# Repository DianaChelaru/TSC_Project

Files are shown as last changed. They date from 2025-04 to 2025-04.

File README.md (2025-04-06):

Acest proiect îmbină mai multe componente electronice conectate la un microcontroler ESP32-C6-WROOM-1-N8, creând o platformă embedded compactă destinată aplicațiilor cu senzoristică, comunicație wireless și o interfață de utilizator minimală. Platforma poate gestiona o serie de funcționalități, inclusiv monitorizarea și interacțiunea cu date în timp real, gestionarea energiei și stocarea datelor.

    Bill of Materials
|Componenta	|Link|	Datasheet|
|---|---|---|
|112A-TAAR-R03_ATTEND |	https://store.comet.bg/en/Catalogue/Product/43497/ |	https://store.comet.bg/en/Catalogue/Product/43497/ |
|744043680IND_4828-WE-TPC_WRE |	https://www.digikey.sg/en/models/1638515 |	https://www.we-online.com/components/products/datasheet/744043680.pdf |
|ADAFRUIT_LEDCHIP-LED0603 |	https://www.snapeda.com/parts/KP-1608SURCK/Kingbright/view-part/?ref=search&t=LED%200603 |	https://www.snapeda.com/parts/KP-1608SURCK/Kingbright/datasheet/ |  
|SAMACSYS_PARTS_USB4110-GF-A|	https://componentsearchengine.com/part-view/USB4110-GF-A/GCT%20(GLOBAL%20CONNECTOR%20TECHNOLOGY) |	https://gct.co/files/drawings/usb4110.pdf |
|BD5229G-TR|	https://componentsearchengine.com/part-view/BD5229G-TR/ROHM%20Semiconductor |	https://datasheet.datasheetarchive.com/originals/distributors/Datasheets_SAMA/f2b9741ef86007909f138d561a359946.pdf |
|CPH3225A|	https://www.snapeda.com/parts/CPH3225A/Seiko+Instruments/view-part/?ref=eda |	https://www.snapeda.com/parts/CPH3225A/Seiko%20Instruments/datasheet/ |
|QWIIC_CONNECTORJS-1MM|	https://www.snapeda.com/parts/PRT-14417/SparkFun/view-part/ |	https://www.snapeda.com/parts/PRT-14417/SparkFun%20Electronics/datasheet/ |
|BUTTON_CUSYOMV1|	https://industry.panasonic.com/global/en/downloads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	| https://industry.panasonic.com/global/en/downloads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 |
|ESP32_WROVER_EAGLE-LTSPICE_CC0402|	https://componentsearchengine.com/part-view/CC0402MRX5R5BB106/YAGEO |	https://componentsearchengine.com/Datasheets/2/CC0402MRX5R5BB106.pdf |
|CPH3225A|	https://www.snapeda.com/parts/CPH3225A/Seiko+Instruments/view-part/?ref=eda |	https://www.snapeda.com/parts/CPH3225A/Seiko%20Instruments/datasheet/ |
|DS3231SN|	https://www.snapeda.com/parts/DS3231SN%23/Analog+Devices/view-part/?ref=eda |	https://www.snapeda.com/parts/DS3231SN%23/Analog%20Devices/datasheet/ |
|ESP32_WROVER_EAGLE-LTSPICE_RR0402|	https://www.snapeda.com/parts/RC0402FR-07226RL/Yageo/view-part/	| https://www.snapeda.com/parts/RC0402FR-07226RL/Yageo/datasheet/ |
|ESP32_WROVER_BME680_BME680|	https://www.snapeda.com/parts/BME680/Bosch/view-part/?welcome=home |	https://www.snapeda.com/parts/BME680/Bosch%20Sensortec/datasheet/ |
|ESP32_WROVER_EAGLE-LTSPICE_CC0402|	https://componentsearchengine.com/Datasheets/2/CC0402MRX5R5BB106.pdf |	https://componentsearchengine.com/part-view/CC0402MRX5R5BB106/YAGEO |
|ESP32_WROVER_SPARKFUN-DISCRETESEMI_MOSFET_PCH-DMG2305UX-7|	https://componentsearchengine.com/part-view/DMG2305UX-7/Diodes%20Incorporated |	https://www.diodes.com//assets/Datasheets/DMG2305UX.pdf |
|ESP32C6_VARISTORCN1812|	https://www.mouser.co.uk/ProductDetail/EPCOS-TDK/B72520T0350K062?qs=dEfas%2FXlABIszF52uu7vrg%3D%3D	| https://www.tdk-electronics.tdk.com/inf/75/db/CTVS_14/Surge_protection_series.pdf |
|ESP32-C6-WROOM-1-N8| 	https://www.snapeda.com/parts/ESP32-C6-WROOM-1-N8/Espressif+Systems/view-part/?ref=eda |	https://www.snapeda.com/parts/ESP32-C6-WROOM-1-N8/Espressif%20Systems/datasheet/ |
|FH34SRJ-24S-0.5SH_99_ |	https://componentsearchengine.com/part-view/XC6220A331MR-G/Torex	| https://product.torexsemi.com/system/files/series/xc6220.pdf |
|MAX17048G+T10|	https://www.snapeda.com/parts/MAX17048G+T10/Analog+Devices/view-part/?ref=eda |	https://www.snapeda.com/parts/MAX17048G+T10/Analog%20Devices/datasheet/ |
|MBR0530|	https://ro.mouser.com/ProductDetail/KYOCERA-AVX/SD0805S020S1R0?qs=jCA%252BPfw4LHbpkAoSnwrdjw%3D%3D |	https://ro.mouser.com/datasheet/2/40/schottky-3165252.pdf |
|PGB1010603MR|	https://www.snapeda.com/parts/PGB1010603MR/Littelfuse/view-part/?ref=eda |	https://www.snapeda.com/parts/PGB1010603MR/Littelfuse%20Inc./datasheet/ |
|MCP73831 |	https://www.digikey.com/en/models/1874108 |	https://ww1.microchip.com/downloads/aemDocuments/documents/APID/ProductDocuments/DataSheets/MCP73831-Family-Data-Sheet-DS20001984H.pdf |
|RCL_CPOL-EUCT3528|	https://ro.mouser.com/ProductDetail/Vishay-Sprague/TR3B106K025C1300?qs=jCGqFXxTmLdffnuDkXzk1g%3D%3D |	https://www.vishay.com/docs/40080/tr3.pdf |
|SI1308EDL-T1-GE3|	https://componentsearchengine.com/part-view/SI1308EDL-T1-GE3/Vishay	| https://componentsearchengine.com/Datasheets/1/SI1308EDL-T1-GE3.pdf |
| SJ |	https://grabcad.com/library/solder-jumpers-1 | 
|USBLC6-2SC6Y |	https://www.snapeda.com/parts/USBLC6-2SC6Y/STMicroelectronics/view-part/?ref=eda	| https://www.snapeda.com/parts/USBLC6-2SC6Y/STMicroelectronics/datasheet/ |
|W25Q512JVEIQ|	https://www.snapeda.com/parts/W25Q512JVEIQ/Winbond+Electronics/view-part/?ref=eda |	https://www.snapeda.com/parts/W25Q512JVEIQ/Winbond%20Electronics/datasheet/ |
|XC6220A331MR-G|	https://componentsearchengine.com/part-view/XC6220A331MR-G/Torex |	https://product.torexsemi.com/system/files/series/xc6220.pdf|

    1. Microcontrolerul ESP32-C6-WROOM-1-N8
Descriere: Acesta este nucleul sistemului nostru și va gestiona toată logica și comunicațiile. Este un microcontroler cu suport pentru Wi-Fi și Bluetooth Low Energy (BLE), având o capacitate de procesare ridicată și multiple periferice integrate.

Componente hardware conectate:

Pinout: Conectarea senzorilor și modulelor va depinde de alegerea pinilor pe care i-am selectat pe ESP32, detaliată în documentație.

Interfețe: ESP32 folosește interfețe precum I2C, SPI și UART pentru a comunica cu componentele periferice.

    2. Senzori
Senzor de temperatură și umiditate (ex. DHT22):

Interfață: Digitală

Rol: Măsurarea temperaturii și umidității în mediu.

Comunicare: Acesta va comunica cu ESP32 folosind pinul GPIO (general-purpose input/output) pentru a obține valorile măsurate.

Senzor de lumină (ex. LDR):

Interfață: Analogică

Rol: Măsurarea intensității luminii din mediu.

Comunicare: Va fi conectat la un pin analogic al ESP32 pentru a permite citirea valorilor de lumină.

    3. RTC (Real-Time Clock)
Componente: Modul RTC (de exemplu, DS3231)

Interfață: I2C

Rol: Ținerea orei și datei, chiar și când microcontrolerul este alimentat cu baterie.

Comunicare: ESP32 se va conecta la RTC prin interfața I2C. Datele și ora vor fi extrase periodic din RTC pentru a menține sincronizarea corectă a sistemului.

    4. Memorie Externă
Componente: Modul de memorie flash (ex. SPI Flash)

Interfață: SPI

Rol: Stocarea datelor de configurare, date temporare, sau orice altă informație care trebuie păstrată între restarturi ale sistemului.

Comunicare: Memoria externă va comunica cu ESP32 prin interfața SPI, permițând citirea și scrierea rapidă a datelor.

    5. Alimentare și Managementul Energiei
Componente:

Regulator de tensiune: Acesta va asigura alimentarea stabilă a întregului sistem.

Baterie Li-Ion: O baterie de 3.7V va fi utilizată pentru a alimenta sistemul într-un mod eficient.

Consumul de Energie:

ESP32 este un microcontroler cu consum variabil, dar în mod normal consumă aproximativ 160 mA în mod activ și mult mai puțin în modul de adormire. Prin gestionarea corectă a modurilor de adormire, se poate reduce consumul total de energie la un nivel foarte scăzut.

Optimizare: Implementarea unui algoritm de gestionare a energiei va permite microcontrolerului să intre în moduri de adormire adâncă în timpul perioadelor de inactivitate, economisind astfel energie.

    6. Interfețe de Comunicație
Wi-Fi (IEEE 802.11b/g/n): ESP32 va fi capabil să comunice prin rețele Wi-Fi pentru a trimite date la servere sau pentru a se conecta la alte dispozitive.

Bluetooth Low Energy (BLE): Pentru comunicații cu alte dispozitive Bluetooth, cum ar fi smartphone-uri sau alte sisteme integrate.

    7. Protecții și Siguranță
Protecție la supratensiune și supracurent: Sistemul va include diode și rezistențe de protecție pentru a preveni daunele cauzate de condiții de tensiune necontrolată.

Siguranța bateriei: Managementul bateriei va include circuite de protecție pentru a preveni supraîncărcarea sau descărcarea excesivă.

    ⚡ Calcule de consum
Acestea sunt estimările de consum pentru fiecare componentă principală a platformei:

ESP32-C6 în modul activ: Aproximativ 80 mA.

Senzori activi (maxim): Între 10-20 mA.

În modul standby: Sub 10 mA, cu ESP în deep sleep și senzorii inactivi.

MCP73831 (încărcare): Până la 500 mA, în funcție de configurare.

Consum optimizat:

LDO XC6220A331MR-G, care este eficient la sarcini joase.

Mod de deep sleep al ESP32-C6 între măsurători.

Control MOSFET pentru a alimenta perifericele doar când este necesar.

    🔌 Pini folosiți pe ESP32-C6
Acestea sunt conexiunile pinilor ESP32-C6 la diversele componente ale proiectului:

|Pin ESP32-C6 |	Funcție	  | Conectat la|
|---|---|---|
|GPIO0 	  |  Buton USER	| BUTTON_CUSTOMV1|
|GPIO1 (TX)  |	UART TX	 | USB4110-GF-A|
|GPIO2 (RX)	 | UART RX	  | USB4110-GF-A|
|GPIO3	 | SDA I2C	  | BME680, DS3231, MAX17048|
|GPIO4	 |  SCL I2C	  | BME680, DS3231, MAX17048|
|GPIO5	 | SPI CS	 |  W25Q512JVEIQ|
|GPIO6	 |  SPI CLK	  | W25Q512JVEIQ|
|GPIO7	 |  SPI MISO	  |  W25Q512JVEIQ|
|GPIO8	 |  SPI MOSI	  |  W25Q512JVEIQ|
|GPIO9	 |  LED	 | ADAFRUIT_LEDCHIP-LED0603|
|GPIO10	 |  MOSFET control |	SI1308EDL-T1-GE3|

diagrama-1

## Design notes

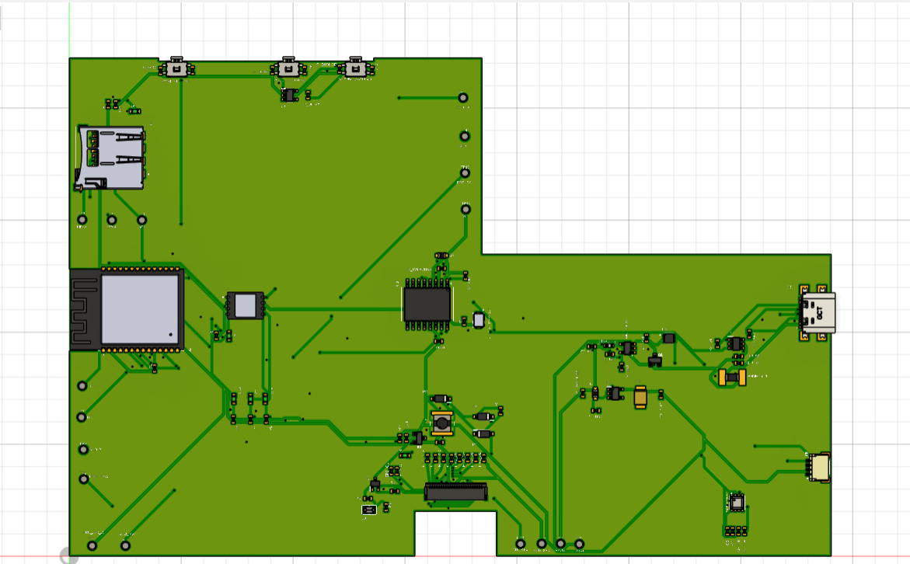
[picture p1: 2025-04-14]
Images/Screenshot 2025-04-14 195516.png

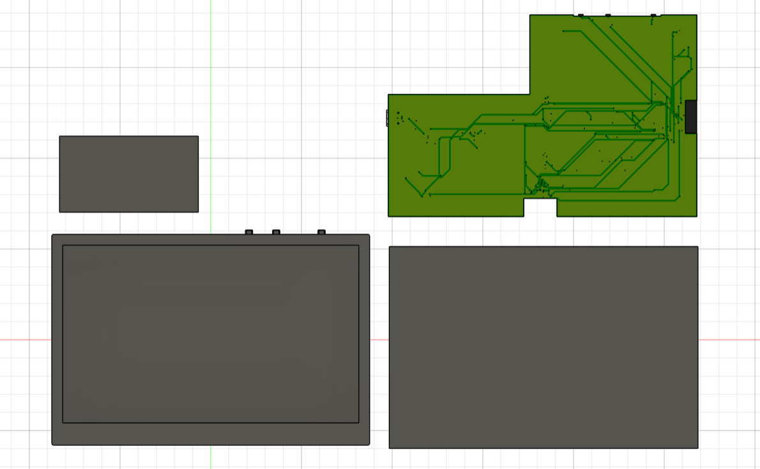
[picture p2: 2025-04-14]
Images/Screenshot 2025-04-11 104446.png

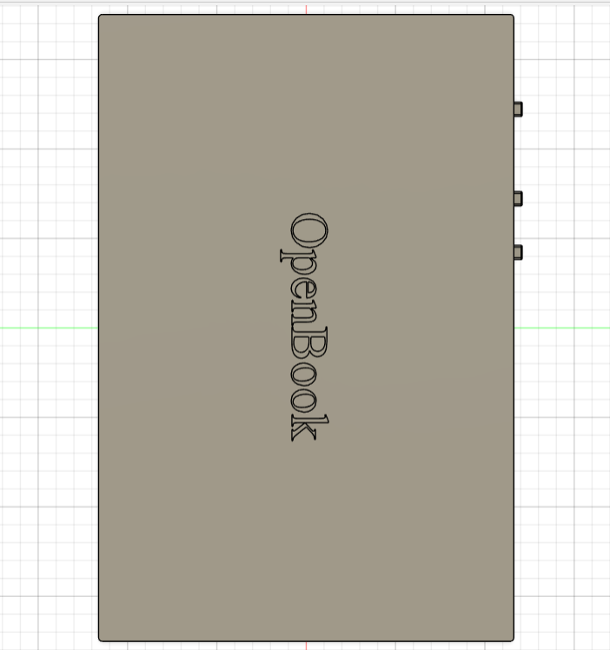
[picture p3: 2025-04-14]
Images/Screenshot 2025-04-11 121247.png

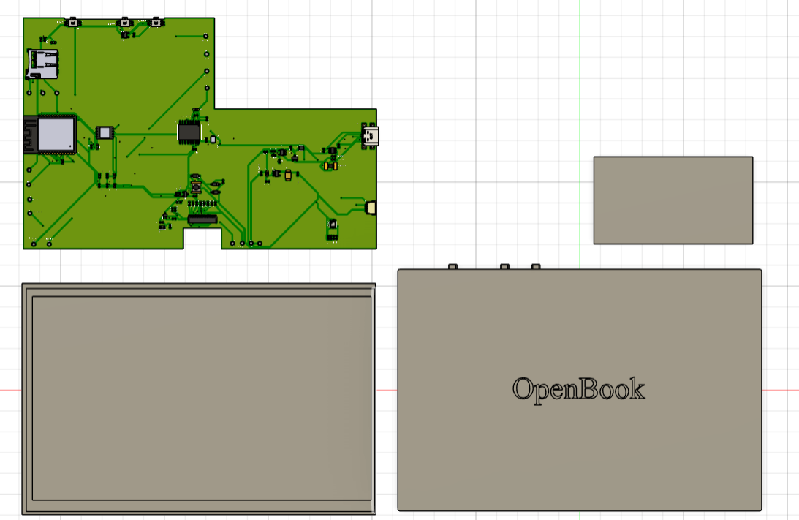
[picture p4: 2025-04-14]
Images/Screenshot 2025-04-11 104347.png

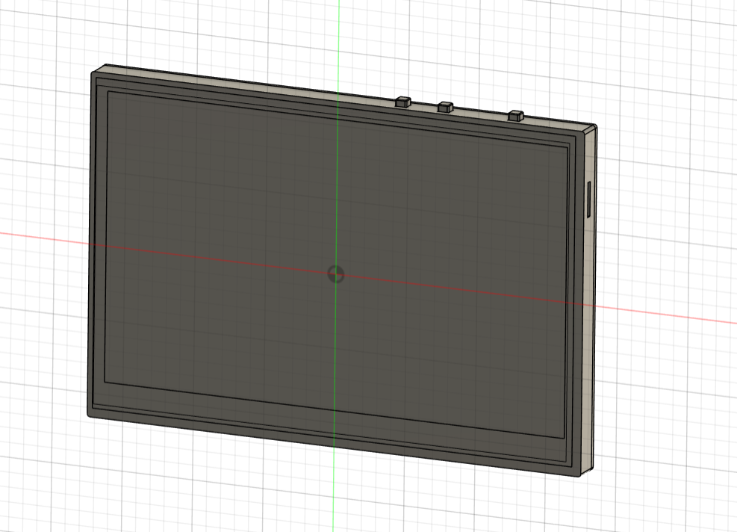
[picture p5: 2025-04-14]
Images/Screenshot 2025-04-11 121353.png

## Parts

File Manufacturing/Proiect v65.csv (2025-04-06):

Qty | Value | Device | Package | Parts | Description | 3V3 | ARROW_PART_NUMBER | ARROW_PRICE-STOCK | AVAILABILITY | CENTROID_NOT_SPECIFIED | CHECK_PRICES | COPYRIGHT | DATASHEET | DESCRIPTION | DIGIKEY_DESCRIPTION | DIGIKEY_PART_NUMBER | EPD_3V3 | EPD_3V3_C | EPD_BUSY | EPD_CS | EPD_DC | EPD_RST | GND_1 | GND_2 | HEIGHT | INT_RTC | LEAD_FREE | MANUFACTURER_NAME | MANUFACTURER_PART_NUMBER | MF | MFR_NAME | MISO | MOSI | MOUSER_PART_NUMBER | MOUSER_PRICE-STOCK | MOUSER_TESTING_PART_NUMBER | MOUSER_TESTING_PRICE-STOCK | MP | MPN | PACKAGE | POPULARITY | PREFIX | PRICE | PROD_ID | PURCHASE-URL | ROHS | RX | SCK | SNAPEDA_LINK | SPICEMODEL | SPICEPREFIX | TEMPERATURE_RANGE_HIGH | TEMPERATURE_RANGE_LOW | TP_SIGNAL_NAME | TX | VALUE | VBAT | VBUS
1 |  | ADAFRUIT_LEDCHIP-LED0603 | ADAFRUIT_CHIP-LED0603 | CHG_LED | LED
1 |  | SJ | SJ | SJ1 | SMD solder JUMPER |  |  |  |  |  |  |  |  |  |  |  |  |  |  |  |  |  |  |  |  |  |  |  |  |  |  |  |  |  |  |  |  |  |  |  | 3
1 | 0.1uF/50V | EAGLE-LTSPICE_CC0402 | EAGLE-LTSPICE_C0402 | EPD_C5 | CAPACITOR, European symbol |  |  |  |  |  |  |  |  |  |  |  |  |  |  |  |  |  |  |  |  |  |  |  |  |  |  |  |  |  |  |  |  |  |  |  |  |  |  |  |  |  |  |  |  | NONE | C
1 | 0.47 | ESP32_WROVER_EAGLE-LTSPICE_RR0402 | ESP32_WROVER_EAGLE-LTSPICE_R0402 | R3 | RESISTOR, European symbol |  |  |  |  |  |  |  |  |  |  |  |  |  |  |  |  |  |  |  |  |  |  |  |  |  |  |  |  |  |  |  |  |  |  |  |  |  |  |  |  |  |  |  |  | NONE | R
1 | 100K | ESP32_WROVER_EAGLE-LTSPICE_RR0402 | ESP32_WROVER_EAGLE-LTSPICE_R0402 | R1_PWRUSB | RESISTOR, European symbol |  |  |  |  |  |  |  |  |  |  |  |  |  |  |  |  |  |  |  |  |  |  |  |  |  |  |  |  |  |  |  |  |  |  |  |  |  |  |  |  |  |  |  |  | NONE | R
8 | 100nF | EAGLE-LTSPICE_CC0402 | EAGLE-LTSPICE_C0402 | C1, C2, C4_USB, C6, C8, C9, C10, C_DELAY | CAPACITOR, European symbol |  |  |  |  |  |  |  |  |  |  |  |  |  |  |  |  |  |  |  |  |  |  |  |  |  |  |  |  |  |  |  |  |  |  |  |  |  |  |  |  |  |  |  |  | NONE | C
1 | 100uF TANT | RCL_CPOL-EUCT3528 | RCL_CT3528 | C3 | POLARIZED CAPACITOR, European symbol |  |  |  |  |  |  |  |  |  |  |  |  |  |  |  |  |  |  |  |  |  |  |  |  |  |  |  |  |  |  |  |  |  |  |  | 0 |  |  |  |  |  |  |  |  |  | C
16 | 10K | ESP32_WROVER_EAGLE-LTSPICE_RR0402 | ESP32_WROVER_EAGLE-LTSPICE_R0402 | R1, R1-PINH, R1-PINH1, R2-PINH, R2-PINH1, R4, R5, R6, R7, R8, R9, R10, R_BOOT, R_CHANGE, R_CL1, R_RESET | RESISTOR, European symbol |  |  |  |  |  |  |  |  |  |  |  |  |  |  |  |  |  |  |  |  |  |  |  |  |  |  |  |  |  |  |  |  |  |  |  |  |  |  |  |  |  |  |  |  | NONE | R
1 | 10uF | EAGLE-LTSPICE_CC0402 | EAGLE-LTSPICE_C0402 | C7 | CAPACITOR, European symbol |  |  |  |  |  |  |  |  |  |  |  |  |  |  |  |  |  |  |  |  |  |  |  |  |  |  |  |  |  |  |  |  |  |  |  |  |  |  |  |  |  |  |  |  | NONE | C
1 | 112A-TAAR-R03_ATTEND | 112A-TAAR-R03_ATTEND | 112ATAARR03ATTEND | J4 | Micro SD Card Socket, Push-Push Type, Top Mount, SMT, H=1.83mm, 10u |  |  |  |  |  |  |  |  | Micro SD Card Socket | Push-Push Type | Top Mount | SMT | H=1.83mm | 10u |  |  |  |  |  |  |  |  |  |  | 1.9mm |  |  | ATTEND | 112A-TAAR-R03 ATTEND
1 | 15 | ESP32_WROVER_EAGLE-LTSPICE_RR0402 | ESP32_WROVER_EAGLE-LTSPICE_R0402 | R_CAPACITOR | RESISTOR, European symbol |  |  |  |  |  |  |  |  |  |  |  |  |  |  |  |  |  |  |  |  |  |  |  |  |  |  |  |  |  |  |  |  |  |  |  |  |  |  |  |  |  |  |  |  | NONE | R
1 | 1uF | EAGLE-LTSPICE_CC0402 | EAGLE-LTSPICE_C0402 | C5 | CAPACITOR, European symbol |  |  |  |  |  |  |  |  |  |  |  |  |  |  |  |  |  |  |  |  |  |  |  |  |  |  |  |  |  |  |  |  |  |  |  |  |  |  |  |  |  |  |  |  | NONE | C
9 | 1uF/50V | EAGLE-LTSPICE_CC0402 | EAGLE-LTSPICE_C0402 | EPD_C1, EPD_C2, EPD_C6, EPD_C7, EPD_C8, EPD_C9, EPD_C10, EPD_C11, EPD_C12 | CAPACITOR, European symbol |  |  |  |  |  |  |  |  |  |  |  |  |  |  |  |  |  |  |  |  |  |  |  |  |  |  |  |  |  |  |  |  |  |  |  |  |  |  |  |  |  |  |  |  | NONE | C
1 | 2.2 | ESP32_WROVER_EAGLE-LTSPICE_RR0402 | ESP32_WROVER_EAGLE-LTSPICE_R0402 | R2 | RESISTOR, European symbol |  |  |  |  |  |  |  |  |  |  |  |  |  |  |  |  |  |  |  |  |  |  |  |  |  |  |  |  |  |  |  |  |  |  |  |  |  |  |  |  |  |  |  |  | NONE | R
1 | 200 | ESP32_WROVER_EAGLE-LTSPICE_RR0402 | ESP32_WROVER_EAGLE-LTSPICE_R0402 | R1_BAT | RESISTOR, European symbol |  |  |  |  |  |  |  |  |  |  |  |  |  |  |  |  |  |  |  |  |  |  |  |  |  |  |  |  |  |  |  |  |  |  |  |  |  |  |  |  |  |  |  |  | NONE | R
2 | 20V/4.2A/52mO/1.4W | ESP32_WROVER_SPARKFUN-DISCRETESEMI_MOSFET_PCH-DMG2305UX-7 | ESP32_WROVER_SPARKFUN-DISCRETESEMI_SOT23-3 | Q1, Q2 | P-channel MOSFETs |  |  |  |  |  |  |  |  |  |  |  |  |  |  |  |  |  |  |  |  |  |  |  |  |  |  |  |  |  |  |  |  |  |  |  |  |  |  | TRAN-14388 |  |  |  |  |  |  |  |  |  |  |  | 20V/4.2A/52mO/1.4W
1 | 2K | ESP32_WROVER_EAGLE-LTSPICE_RR0402 | ESP32_WROVER_EAGLE-LTSPICE_R0402 | R2_BAT | RESISTOR, European symbol |  |  |  |  |  |  |  |  |  |  |  |  |  |  |  |  |  |  |  |  |  |  |  |  |  |  |  |  |  |  |  |  |  |  |  |  |  |  |  |  |  |  |  |  | NONE | R
5 | 4.7uF | EAGLE-LTSPICE_CC0402 | EAGLE-LTSPICE_C0402 | C1_BAT, C1_BAT1, C1_BAT2, C2_BAT, C5_USB | CAPACITOR, European symbol |  |  |  |  |  |  |  |  |  |  |  |  |  |  |  |  |  |  |  |  |  |  |  |  |  |  |  |  |  |  |  |  |  |  |  |  |  |  |  |  |  |  |  |  | NONE | C
1 | 4.7uF/25V | EAGLE-LTSPICE_CC0402 | EAGLE-LTSPICE_C0402 | C4 | CAPACITOR, European symbol |  |  |  |  |  |  |  |  |  |  |  |  |  |  |  |  |  |  |  |  |  |  |  |  |  |  |  |  |  |  |  |  |  |  |  |  |  |  |  |  |  |  |  |  | NONE | C
2 | 5k1 | ESP32_WROVER_EAGLE-LTSPICE_RR0402 | ESP32_WROVER_EAGLE-LTSPICE_R0402 | R2-USB, R2-USB1 | RESISTOR, European symbol |  |  |  |  |  |  |  |  |  |  |  |  |  |  |  |  |  |  |  |  |  |  |  |  |  |  |  |  |  |  |  |  |  |  |  |  |  |  |  |  |  |  |  |  | NONE | R
1 | 68uH | 744043680IND_4828-WE-TPC_WRE | IND_4828-WE-TPC_WRE | L1 |  |  |  |  |  |  |  | Copyright (C) 2024 Ultra Librarian. All rights reserved. |  |  |  |  |  |  |  |  |  |  |  |  |  |  |  |  | 744043680 |  | Wurth Electronics
1 | BD5229G-TR | BD5229G-TR | SOT95P280X125-5N | IC1 | Voltage Detector with Adjustable Delay Time: CMOS processes are utilized to develop high precision, low current consumption CMOS reset ICs that allow arbitrary setting of the delay time. The extensive lineup includes both Nch Open Drain and CMOS output types in a wide range of detection voltages (from 2.3V to 6.0V, in 0.1V steps), enabling selection of the ideal solution based on customer requirements. In addition, the entire series is of course both lead-free and RoHS-compliant. |  |  |  |  |  |  |  |  | Voltage Detector with Adjustable Delay Time: CMOS processes are utilized to develop high precision | low current consumption CMOS reset ICs that allow arbitrary setting of the delay time. The extensive lineup includes both Nch Open Drain and CMOS output types in a wide range of detection voltages (from 2.3V to 6.0V | in 0.1V steps) | enabling selection of the ideal solution based on customer requirements. In addition | the entire series is of course both lead-free and RoHS-compliant. |  |  |  |  |  |  |  |  |  |  | 1.25mm |  |  | ROHM Semiconductor | BD5229G-TR |  |  |  |  | 755-BD5229G-TR | https://www.mouser.co.uk/ProductDetail/ROHM-Semiconductor/BD5229G-TR?qs=4kLU8WoGk0vvnhrrYwdszw%3D%3D
3 | BUTTON_CUSYOMV1 | BUTTON_CUSYOMV1 | MYBUTTON | BOOT_BUTTON, CHANGE_BUTTON, RESET_BUTTON
1 | CPH3225A | CPH3225A | CAPCP3225X100N | C10_SUPERCAP | Cap 0.011F 3.3V 1210 Flat Check availability |  |  |  | Not in stock |  | https://www.snapeda.com/parts/CPH3225A/Seiko+Instruments/view-part/?ref=eda |  |  | 11 mF (EDLC) Supercapacitor 3.3 V 1210 (3225 Metric) - - |  |  |  |  |  |  |  |  |  |  |  |  |  |  |  | Seiko Instruments |  |  |  |  |  |  |  | CPH3225A |  | 1210 Seiko |  |  | None |  | https://www.snapeda.com/api/url_track_click_mouser/?unipart_id=562593&manufacturer=Seiko Instruments&part_name=CPH3225A&search_term=None |  |  |  | https://www.snapeda.com/parts/CPH3225A/Seiko+Instruments/view-part/?ref=snap
1 | DS3231SN# | DS3231SN# | SOIC127P1032X265-16N | U3 | Real Time Clock Serial 16-Pin SOIC W T/R Check availability |  |  |  | In Stock |  | https://www.snapeda.com/parts/DS3231SN%23/Analog+Devices/view-part/?ref=eda |  |  | Extremely Accurate I²C-Integrated RTC/TCXO/Crystal |  |  |  |  |  |  |  |  |  |  |  |  |  |  |  | Analog Devices |  |  |  |  |  |  |  | DS3231SN# |  | SOIC-16 Maxim |  |  | None |  | https://www.snapeda.com/api/url_track_click_mouser/?unipart_id=99048&manufacturer=Analog Devices&part_name=DS3231SN#&search_term=None |  |  |  | https://www.snapeda.com/parts/DS3231SN%23/Analog+Devices/view-part/?ref=snap
1 | ESP32-C6-WROOM-1-N8 | ESP32-C6-WROOM-1-N8 | XCVR_ESP32-C6-WROOM-1-N8 | U2 | Check availability |  |  |  | In Stock |  | https://www.snapeda.com/parts/ESP32-C6-WROOM-1-N8/Espressif+Systems/view-part/?ref=eda |  |  | Multiprotocol Modules ESP32-C6 module | Wi-Fi 6 in 2.4 GHz band | Bluetooth 5 | Zigbee 3.0 and Thread. ESP34-WROOM Compatible - ENGINEERING SAMPLE |  |  |  |  |  |  |  |  |  |  |  |  |  |  |  | Espressif Systems |  |  |  |  |  |  |  | ESP32-C6-WROOM-1-N8 |  | None |  |  | None |  |  |  |  |  | https://www.snapeda.com/parts/ESP32-C6-WROOM-1-N8/Espressif+Systems/view-part/?ref=snap
1 | ESP32C6_VARISTORCN1812 | ESP32C6_VARISTORCN1812 | ESP32C6_VARISTOR_CT/CN1812 | PFMF.050.1 | VARISTOR |  |  |  |  |  |  |  |  |  |  |  |  |  |  |  |  |  |  |  |  |  |  |  |  |  |  |  |  |  |  |  |  |  |  |  | 0
2 | ESP32_WROVER_AVX---SD0805S020S1R0_AVX_SD0805S020S1R0_0_0AVX_SD0805S020S1R0_0_0 | ESP32_WROVER_AVX---SD0805S020S1R0_AVX_SD0805S020S1R0_0_0AVX_SD0805S020S1R0_0_0 | ESP32_WROVER_AVX---SD0805S020S1R0_AVX_SD0805S020S1R0_0 | D2, D7 | Schottky Barrier Rectifier Diode |  |  |  |  | No |  |  | http://datasheets.avx.com/schottky.pdf |  | DIODE SCHOTTKY 20V 1A 0805 | 478-7800-1-ND |  |  |  |  |  |  |  |  |  |  | yes |  |  | AVX |  |  |  | 581-SD0805S020S1R0 |  |  |  |  |  | 0805 (2012 metric) |  | D |  |  |  | yes |  |  |  |  |  | +125°C | -55°C
1 | ESP32_WROVER_BME680_BME680 | ESP32_WROVER_BME680_BME680 | ESP32_WROVER_BME680_PSON80P300X300X100-8N | SENSOR2 | Integrated Environmental Unit |  |  |  | Unavailable |  |  |  |  | Integrated Environmental Unit |  |  |  |  |  |  |  |  |  |  |  |  |  |  |  | Bosch Sensortec |  |  |  |  |  |  |  | BME680 |  | LGA-8 Bosch Tools |  |  | None
1 | ESP32_WROVER_SPARKFUN-IC-POWER_MCP73831 | ESP32_WROVER_SPARKFUN-IC-POWER_MCP73831 | ESP32_WROVER_SPARKFUN-IC-POWER_SOT23-5 | MCP73831 | MCP73831T Li-Ion, Li-Pol Controller |  |  |  |  |  |  |  |  |  |  |  |  |  |  |  |  |  |  |  |  |  |  |  |  |  |  |  |  |  |  |  |  |  |  |  |  |  |  | IC-09995
1 | FH34SRJ-24S-0.5SH_99_ | FH34SRJ-24S-0.5SH_99_ | FH34SRJ24S05SH99 | J1 | (0.50mm) Surface Mount, Right Angle |  |  |  |  |  |  |  |  | 24 Position FFC | FPC Connector Contacts | (0.50mm) Surface Mount | Right Angle |  |  |  |  |  |  |  |  |  |  | 1.1mm |  |  | Hirose | FH34SRJ-24S-0.5SH(99) |  |  |  |  | 798-FH34SRJ24S05SH99 | https://www.mouser.co.uk/ProductDetail/Hirose-Connector/FH34SRJ-24S-0.5SH99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
1 | MAX17048G+T10 | MAX17048G+T10 | SON50P200X200X80-9N | U4 | Check availability |  |  |  | In Stock |  | https://www.snapeda.com/parts/MAX17048G+T10/Analog+Devices/view-part/?ref=eda |  |  | 3µA 1-Cell/2-Cell Fuel Gauge with ModelGauge |  |  |  |  |  |  |  |  |  |  |  |  |  |  |  | Analog Devices |  |  |  |  |  |  |  | MAX17048G+T10 |  | TDFN-8 Maxim |  |  | None |  | https://www.snapeda.com/api/url_track_click_mouser/?unipart_id=329239&manufacturer=Analog Devices&part_name=MAX17048G+T10&search_term=None |  |  |  | https://www.snapeda.com/parts/MAX17048G+T10/Analog+Devices/view-part/?ref=snap
3 | MBR0530 | MBR0530 | SOD3716X135N | D3, D4, D5 | ON SEMICONDUCTOR - MBR0530 - DIODE, SCHOTTKY, 0.5A, 30V, SOD-123 |  |  |  | In Stock |  | https://www.snapeda.com/parts/MBR0530/Onsemi/view-part/?ref=eda |  |  | Diode Schottky 30 V 500mA Surface Mount SOD-123 |  |  |  |  |  |  |  |  |  |  |  |  |  |  |  | ON Semiconductor |  |  |  |  |  |  |  | MBR0530 |  | SOD-123-2 ON Semiconductor |  |  | None |  | https://www.snapeda.com/api/url_track_click_mouser/?unipart_id=179458&manufacturer=ON Semiconductor&part_name=MBR0530&search_term=None |  |  |  | https://www.snapeda.com/parts/MBR0530/Onsemi/view-part/?ref=snap
6 | PGB1010603MR | PGB1010603MR | DIOC1608X36N | D6, D8, D9, D10, D11, D12 | Check availability |  |  |  | In Stock |  | https://www.snapeda.com/parts/PGB1010603MR/Littelfuse/view-part/?ref=eda |  |  | 150V (Typ) Clamp - Ipp Tvs Diode Surface Mount 0603 (1608 Metric) |  |  |  |  |  |  |  |  |  |  |  |  |  |  |  | Littelfuse Inc. |  |  |  |  |  |  |  | PGB1010603MR |  | 0603 Littelfuse Inc. |  |  | None |  | https://www.snapeda.com/api/url_track_click_mouser/?unipart_id=5659453&manufacturer=Littelfuse Inc.&part_name=PGB1010603MR&search_term=None |  |  |  | https://www.snapeda.com/parts/PGB1010603MR/Littelfuse/view-part/?ref=snap
1 | QWIIC_RIGHT_ANGLE | QWIIC_CONNECTORJS-1MM | JST04_1MM_RA | J3 | SparkFun I2C Standard Qwiic Connector |  |  |  |  |  |  |  |  |  |  |  |  |  |  |  |  |  |  |  |  |  |  |  |  |  |  |  |  |  |  |  |  |  |  |  |  |  |  | CONN-13694 |  |  |  |  |  |  |  |  |  |  |  | QWIIC_RIGHT_ANGLE
1 | SAMACSYS_PARTS_USB4110-GF-A | SAMACSYS_PARTS_USB4110-GF-A | SAMACSYS_PARTS_USB4110GFA | J2 | CONN USB 2.0 TYPE-C R/A SMT |  |  |  |  |  |  |  |  | CONN USB 2.0 TYPE-C R/A SMT |  |  |  |  |  |  |  |  |  |  | 3.26mm |  |  | GCT (GLOBAL CONNECTOR TECHNOLOGY) | USB4110-GF-A |  |  |  |  | 640-USB4110-GF-A | https://www.mouser.co.uk/ProductDetail/GCT/USB4110-GF-A?qs=KUoIvG%2F9IlYiZvIXQjyJeA%3D%3D
1 | SI1308EDL-T1-GE3 | SI1308EDL-T1-GE3 | SOT65P210X110-3N | Q3 | MOSFET N-Ch 30V 1.5A TrenchFET SC70 Vishay Si1308EDL-T1-GE3 N-channel MOSFET Transistor, 1.5 A, 30 V, 3-Pin SC-70 |  |  |  | In Stock |  | https://www.snapeda.com/parts/SI1308EDL-T1-GE3/Vishay+Siliconix/view-part/?ref=eda |  |  | Si1308EDL-T1-GE3 N-channel MOSFET Transistor | 1.5 A | 30 V | 3-Pin SC-70 | Siliconix / Vishay SI1308EDL-T1-GE3 |  |  |  |  |  |  |  |  |  |  |  |  |  |  |  | Vishay Siliconix |  |  |  |  |  |  |  | SI1308EDL-T1-GE3 |  | SOT-323 Vishay Semiconductor |  |  | None |  | https://www.snapeda.com/api/url_track_click_mouser/?unipart_id=274603&manufacturer=Vishay Siliconix&part_name=SI1308EDL-T1-GE3&search_term=None |  |  |  | https://www.snapeda.com/parts/SI1308EDL-T1-GE3/Vishay+Siliconix/view-part/?ref=snap
17 | TPTP20R | TPTP20R | TP20R | TP1, TP2, TP3, TP4, TP5, TP6, TP7, TP8, TP9, TP10, TP11, TP12, TP13, TP14, TP15, TP16, TP17 | Test pad |  |  |  |  |  |  |  |  |  |  |  |  |  |  |  |  |  |  |  |  |  |  |  |  |  |  |  |  |  |  |  |  |  |  |  | 2
1 | USBLC6-2SC6Y | USBLC6-2SC6Y | SOT95P280X145-6N | D1 | Low Cap. ESD Protection Auto SOT-23-6 STMicroelectronics USBLC6-2SC6Y, Dual Uni-Directional TVS Diode Array, 6-Pin SOT-23 |  |  |  | In Stock |  | https://www.snapeda.com/parts/USBLC6-2SC6Y/STMicroelectronics/view-part/?ref=eda |  |  | 17V Clamp 5A (8/20µs) Ipp Tvs Diode Surface Mount SOT-23-6 |  |  |  |  |  |  |  |  |  |  |  |  |  |  |  | STMicroelectronics |  |  |  |  |  |  |  | USBLC6-2SC6Y |  | SOT-23-6 STMicroelectronics |  |  | None |  |  |  |  |  | https://www.snapeda.com/parts/USBLC6-2SC6Y/STMicroelectronics/view-part/?ref=snap
1 | W25Q512JVEIQ | W25Q512JVEIQ | SON127P600X800X80-9N | U1 | Check availability |  |  |  | In Stock |  | https://www.snapeda.com/parts/W25Q512JVEIQ/Winbond+Electronics/view-part/?ref=eda |  |  | FLASH - NOR Memory IC 512Mb (64M x 8) SPI - Quad I/O 133 MHz 8-WSON (8x6) |  |  |  |  |  |  |  |  |  |  |  |  |  |  |  | Winbond Electronics |  |  |  |  |  |  |  | W25Q512JVEIQ |  | Package |  |  | None |  |  |  |  |  | https://www.snapeda.com/parts/W25Q512JVEIQ/Winbond+Electronics/view-part/?ref=snap
1 | XC6220A331MR-G | XC6220A331MR-G | SOT95P280X120-5N | IC4 | LDO Voltage Regulators |  |  |  |  |  |  |  |  | LDO Voltage Regulators |  |  |  |  |  |  |  |  |  |  | 1.2mm |  |  | Torex | XC6220A331MR-G |  |  |  |  | 865-XC6220A331MR-G | https://www.mouser.co.uk/ProductDetail/Torex-Semiconductor/XC6220A331MR-G?qs=AsjdqWjXhJ8ZSWznL1J0gg%3D%3D

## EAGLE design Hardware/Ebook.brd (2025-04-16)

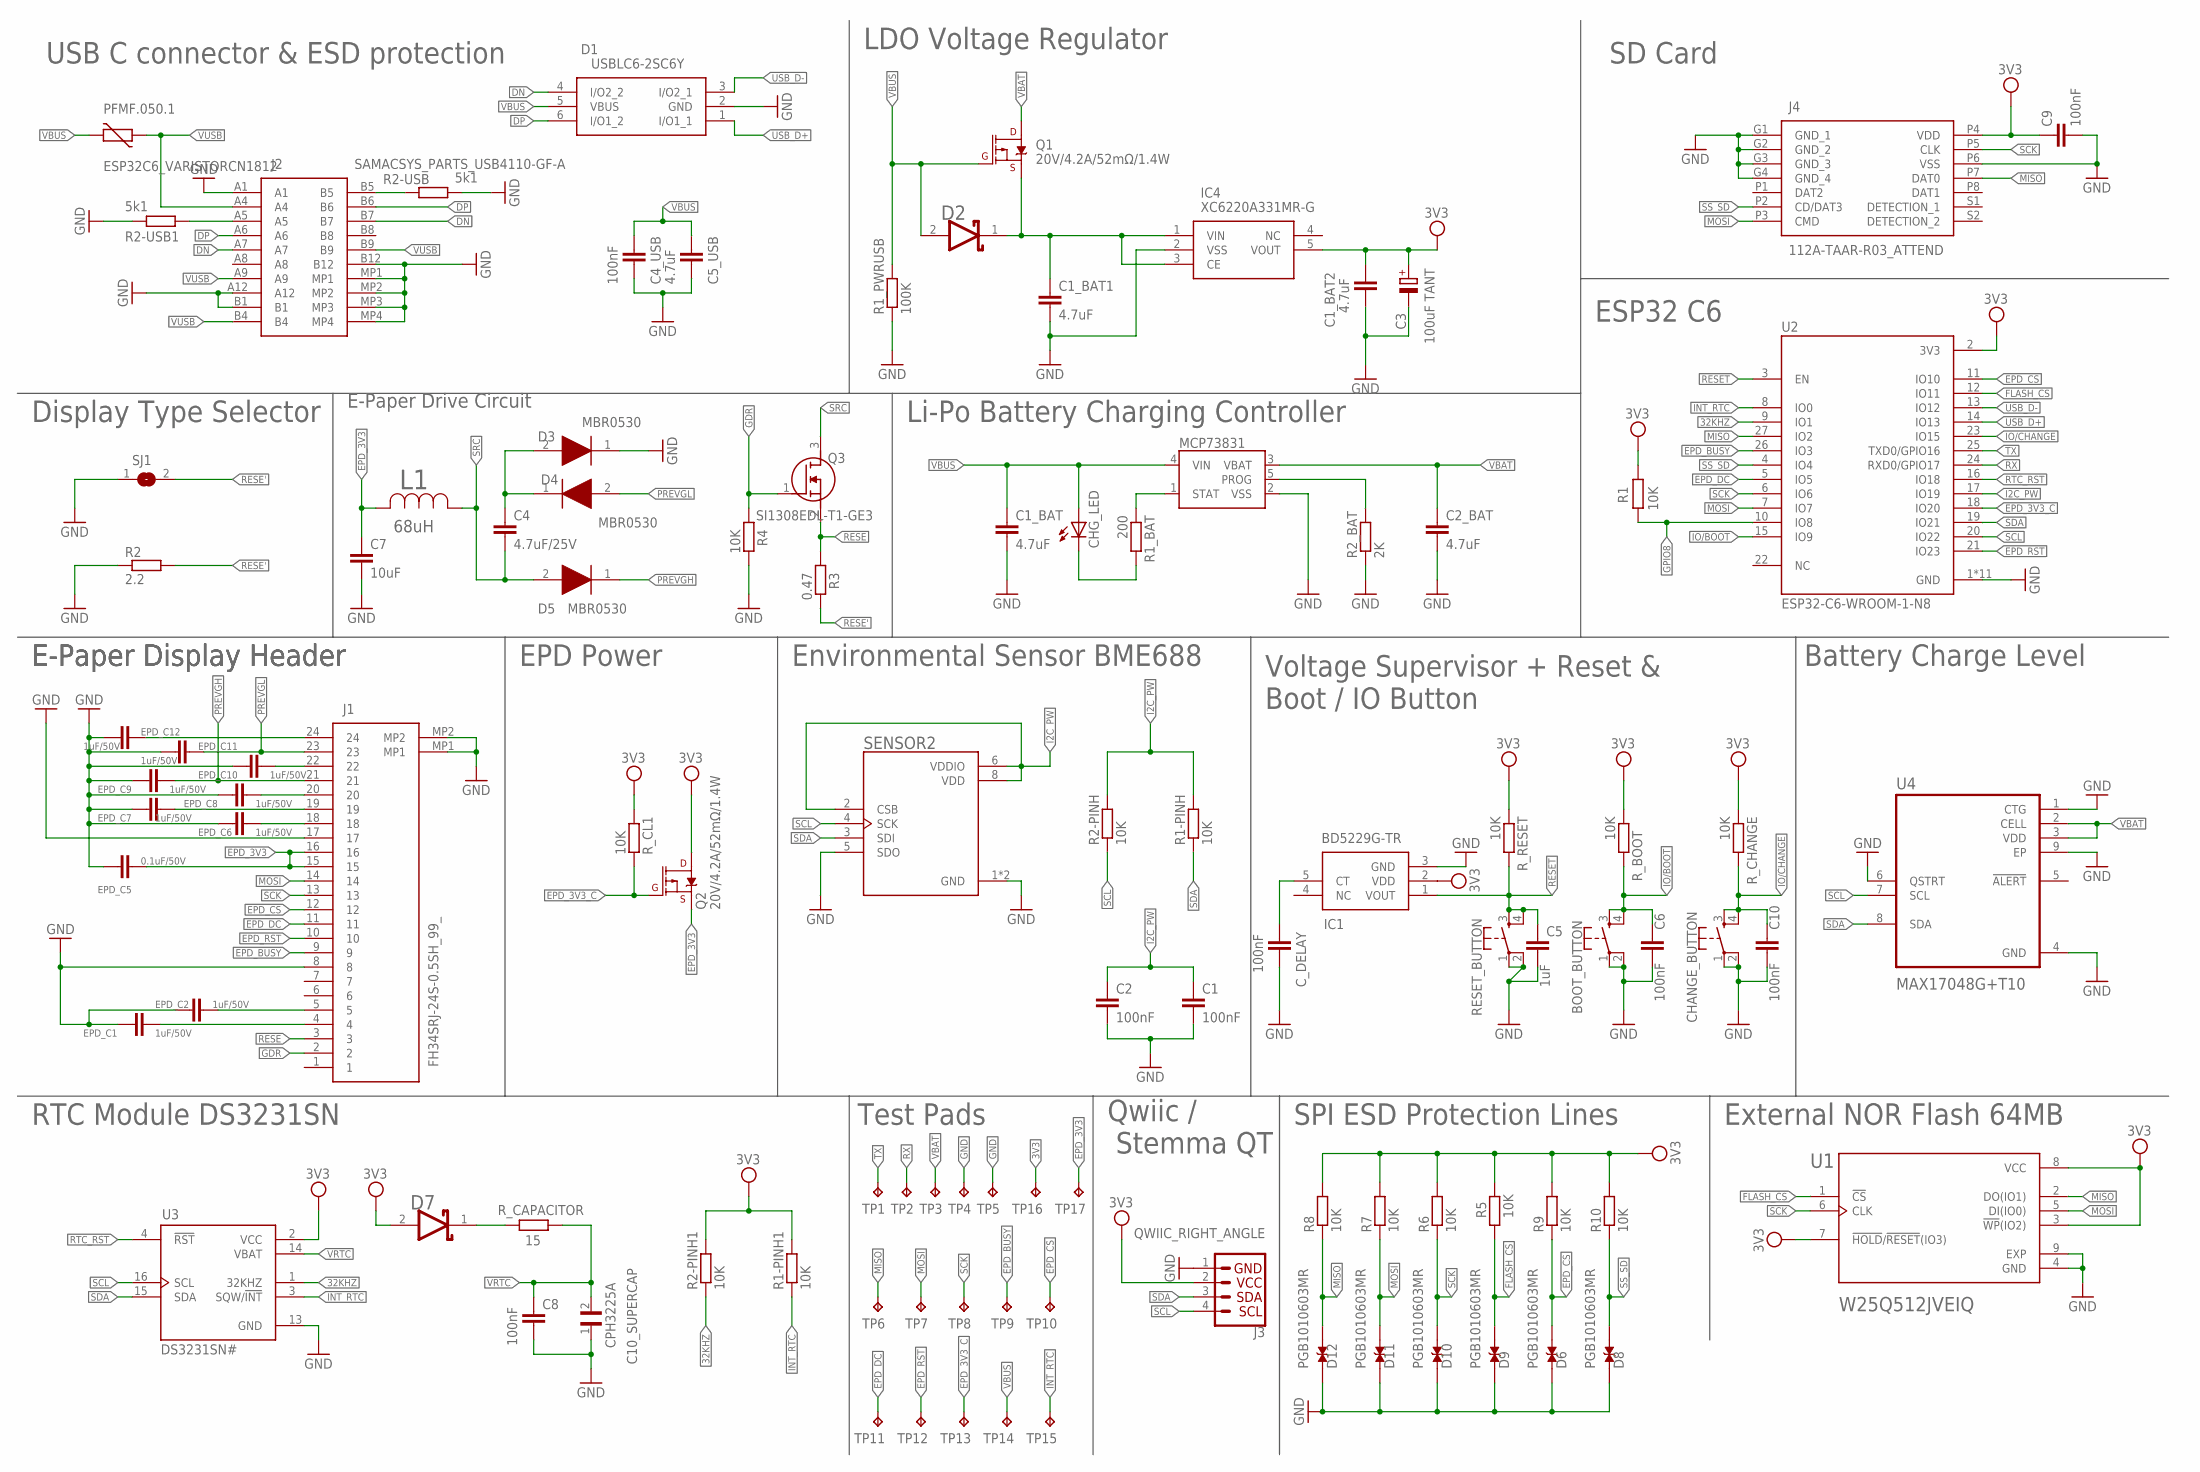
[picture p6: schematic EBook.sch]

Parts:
BOOT_BUTTON: BUTTON_CUSYOMV1; MYBUTTON
C1, C2, C4_USB, C6, C8, C9, C10: 100nF; EAGLE-LTSPICE_C0402
C1_BAT, C1_BAT1, C1_BAT2, C2_BAT, C5_USB: 4.7uF; EAGLE-LTSPICE_C0402
C3: 100uF TANT; RCL_CT3528
C4: 4.7uF/25V; EAGLE-LTSPICE_C0402
C5: 1uF; EAGLE-LTSPICE_C0402
C7: 10uF; EAGLE-LTSPICE_C0402
C10_SUPERCAP: CPH3225A; CAPCP3225X100N
CHANGE_BUTTON: BUTTON_CUSYOMV1; MYBUTTON
CHG_LED: ADAFRUIT_LEDCHIP-LED0603; ADAFRUIT_CHIP-LED0603
C_DELAY: 100nF; EAGLE-LTSPICE_C0402
D1: USBLC6-2SC6Y; SOT95P280X145-6N
D2, D7: ESP32_WROVER_AVX---SD0805S020S1R0_AVX_SD0805S020S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; ESP32_WROVER_AVX---SD0805S020S1R0_AVX_SD0805S020S1R0_0
D3, D4, D5: MBR0530; SOD3716X135N
D6, D8, D9, D10, D11, D12: PGB1010603MR; DIOC1608X36N
EPD_C1, EPD_C2, EPD_C6, EPD_C7, EPD_C8, EPD_C9, EPD_C10, EPD_C11, EPD_C12: 1uF/50V; EAGLE-LTSPICE_C0402
EPD_C5: 0.1uF/50V; EAGLE-LTSPICE_C0402
IC1: BD5229G-TR; SOT95P280X125-5N
IC4: XC6220A331MR-G; SOT95P280X120-5N
J1: FH34SRJ-24S-0.5SH_99_; FH34SRJ24S05SH99
J2: SAMACSYS_PARTS_USB4110-GF-A; SAMACSYS_PARTS_USB4110GFA
J3: QWIIC_RIGHT_ANGLE; JST04_1MM_RA
J4: 112A-TAAR-R03_ATTEND; 112ATAARR03ATTEND
L1: 68uH; IND_4828-WE-TPC_WRE
MCP73831: ESP32_WROVER_SPARKFUN-IC-POWER_MCP73831; ESP32_WROVER_SPARKFUN-IC-POWER_SOT23-5
PFMF.050.1: ESP32C6_VARISTORCN1812; ESP32C6_VARISTOR_CT/CN1812
Q1, Q2: 20V/4.2A/52mΩ/1.4W; ESP32_WROVER_SPARKFUN-DISCRETESEMI_SOT23-3
Q3: SI1308EDL-T1-GE3; SOT65P210X110-3N
R1, R1-PINH, R1-PINH1, R2-PINH, R2-PINH1, R4, R5, R6, R7, R8, R9, R10: 10K; ESP32_WROVER_EAGLE-LTSPICE_R0402
R1_BAT: 200; ESP32_WROVER_EAGLE-LTSPICE_R0402
R1_PWRUSB: 100K; ESP32_WROVER_EAGLE-LTSPICE_R0402
R2: 2.2; ESP32_WROVER_EAGLE-LTSPICE_R0402
R2-USB, R2-USB1: 5k1; ESP32_WROVER_EAGLE-LTSPICE_R0402
R2_BAT: 2K; ESP32_WROVER_EAGLE-LTSPICE_R0402
R3: 0.47; ESP32_WROVER_EAGLE-LTSPICE_R0402
RESET_BUTTON: BUTTON_CUSYOMV1; MYBUTTON
R_BOOT: 10K; ESP32_WROVER_EAGLE-LTSPICE_R0402
R_CAPACITOR: 15; ESP32_WROVER_EAGLE-LTSPICE_R0402
R_CHANGE: 10K; ESP32_WROVER_EAGLE-LTSPICE_R0402
R_CL1: 10K; ESP32_WROVER_EAGLE-LTSPICE_R0402
R_RESET: 10K; ESP32_WROVER_EAGLE-LTSPICE_R0402
SENSOR2: ESP32_WROVER_BME680_BME680; ESP32_WROVER_BME680_PSON80P300X300X100-8N
SJ1: SJ
TP1, TP2, TP3, TP4, TP5, TP6, TP7, TP8, TP9, TP10, TP11, TP12, TP13, TP14, TP15, TP16, TP17: TPTP20R; TP20R
U1: W25Q512JVEIQ; SON127P600X800X80-9N
U2: ESP32-C6-WROOM-1-N8; XCVR_ESP32-C6-WROOM-1-N8
U3: DS3231SN#; SOIC127P1032X265-16N
U4: MAX17048G+T10; SON50P200X200X80-9N

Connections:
3V3: C1_BAT2.1, C3.+, C9.1, D7.2 (ANODE), IC1.2 (VDD), IC4.5 (VOUT), J3.2, J4.P4 (VDD), Q2.3 (D), R1.1, R1-PINH1.2, R2-PINH1.2, R5.2, R6.2, R7.2, R8.2, R9.2, R10.2, R_BOOT.1, R_CHANGE.1, R_CL1.1, R_RESET.1, TP16.TP, U1.3 (!WP!(IO2)), U1.7 (!HOLD!/!RESET!(IO3)), U1.8 (VCC), U2.2 (3V3), U3.2 (VCC)
32KHZ: R2-PINH1.1, U2.9 (IO1), U3.1 (32KHZ)
DN: D1.4 (I/O2_2), J2.A7, J2.B7
DP: D1.6 (I/O1_2), J2.A6, J2.B6
EPD_3V3: C7.1, EPD_C5.1, J1.15, J1.16, L1.2, Q2.2 (S), TP17.TP
EPD_3V3_C: Q2.1 (G), R_CL1.2, TP13.TP, U2.18 (IO20)
EPD_BUSY: J1.9, TP9.TP, U2.26 (IO3)
EPD_CS: D6.2, J1.12, R9.1, TP10.TP, U2.11 (IO10)
EPD_DC: J1.11, TP11.TP, U2.5 (IO5)
EPD_RST: J1.10, TP12.TP, U2.21 (IO23)
FLASH_CS: D9.2, R5.1, U1.1 (!CS), U2.12 (IO11)
GDR: J1.2, Q3.1 (G), R4.1
GND: BOOT_BUTTON.1, BOOT_BUTTON.2, C1.2, C1_BAT.2, C1_BAT1.2, C1_BAT2.2, C2.2, C2_BAT.2, C3.-, C4_USB.2, C5.2, C5_USB.2, C6.2, C7.2, C8.2, C9.2, C10.2, C10_SUPERCAP.1, CHANGE_BUTTON.1, CHANGE_BUTTON.2, C_DELAY.2, D1.2 (GND), D3.1 (K), D6.1, D8.1, D9.1, D10.1, D11.1, D12.1, EPD_C1.2, EPD_C2.2, EPD_C5.2, EPD_C6.2, EPD_C7.2, EPD_C8.2, EPD_C9.2, EPD_C10.2, EPD_C11.2, EPD_C12.2, IC1.3 (GND), IC4.2 (VSS), J1.8, J1.17, J1.MP1, J1.MP2, J2.A1, J2.A12, J2.B1, J2.B12, J2.MP1, J2.MP2, J2.MP3, J2.MP4, J3.1, J4.G1 (GND_1), J4.G2 (GND_2), J4.G3 (GND_3), J4.G4 (GND_4), J4.P6 (VSS), MCP73831.2 (VSS), R1_PWRUSB.1, R2.1, R2-USB.2, R2-USB1.1, R2_BAT.1, R4.2, RESET_BUTTON.1, RESET_BUTTON.2, SENSOR2.1 (GND), SENSOR2.5 (SDO), SENSOR2.7 (GND), SJ1.1, TP4.TP, TP5.TP, U1.4 (GND), U1.9 (EXP), U2.1 (GND), U2.28 (GND), U2.29_1 (GND), U2.29_2 (GND), U2.29_3 (GND), U2.29_4 (GND), U2.29_5 (GND), U2.29_6 (GND), U2.29_7 (GND), U2.29_8 (GND), U2.29_9 (GND), U3.13 (GND), U4.1 (CTG), U4.4 (GND), U4.6 (QSTRT), U4.9 (EP)
GPIO8: R1.2, U2.10 (IO8)
I2C_PW: C1.1, C2.1, R1-PINH.2, R2-PINH.2, SENSOR2.2 (CSB), SENSOR2.6 (VDDIO), SENSOR2.8 (VDD), U2.17 (IO19)
INT_RTC: R1-PINH1.1, TP15.TP, U2.8 (IO0), U3.3 (SQW/!INT)
IO/BOOT: BOOT_BUTTON.3, BOOT_BUTTON.4, C6.1, R_BOOT.2, U2.15 (IO9)
IO/CHANGE: C10.1, CHANGE_BUTTON.3, CHANGE_BUTTON.4, R_CHANGE.2, U2.23 (IO15)
MISO: D12.2, J4.P7 (DAT0), R8.1, TP6.TP, U1.2 (DO(IO1)), U2.27 (IO2)
MOSI: D11.2, J1.14, J4.P3 (CMD), R7.1, TP7.TP, U1.5 (DI(IO0)), U2.7 (IO7)
unnamed: J2.B5, R2-USB.1
unnamed: EPD_C6.1, J1.18
unnamed: J2.A5, R2-USB1.2
unnamed: C1_BAT1.1, D2.1 (CATHODE), IC4.1 (VIN), IC4.3 (CE), Q1.2 (S)
unnamed: C4.1, D3.2 (A), D4.1 (K)
unnamed: EPD_C7.1, J1.19
unnamed: MCP73831.5 (PROG), R2_BAT.2
unnamed: MCP73831.1 (STAT), R1_BAT.1
unnamed: CHG_LED.C, R1_BAT.2
unnamed: C_DELAY.1, IC1.5 (CT)
unnamed: EPD_C10.1, J1.22
unnamed: EPD_C2.1, J1.5
unnamed: D7.1 (CATHODE), R_CAPACITOR.2
unnamed: EPD_C12.1, J1.24
unnamed: EPD_C8.1, J1.20
unnamed: EPD_C1.1, J1.4
PREVGH: D5.1 (K), EPD_C9.1, J1.21
PREVGL: D4.2 (A), EPD_C11.1, J1.23
RESE: J1.3, Q3.2 (S), R3.1
RESE': R2.2, R3.2, SJ1.2
RESET: C5.1, IC1.1 (VOUT), RESET_BUTTON.3, RESET_BUTTON.4, R_RESET.2, U2.3 (EN)
RTC_RST: U2.16 (IO18), U3.4 (!RST)
RX: TP2.TP, U2.24 (RXD0/GPIO17)
SCK: D10.2, J1.13, J4.P5 (CLK), R6.1, TP8.TP, U1.6 (CLK), U2.6 (IO6)
SCL: J3.4, R2-PINH.1, SENSOR2.4 (SCK), U2.20 (IO22), U3.16 (SCL), U4.7 (SCL)
SDA: J3.3, R1-PINH.1, SENSOR2.3 (SDI), U2.19 (IO21), U3.15 (SDA), U4.8 (SDA)
SRC: C4.2, D5.2 (A), L1.1, Q3.3 (D)
SS_SD: D8.2, J4.P2 (CD/DAT3), R10.1, U2.4 (IO4)
TX: TP1.TP, U2.25 (TXD0/GPIO16)
USB_D+: D1.1 (I/O1_1), U2.14 (IO13)
USB_D-: D1.3 (I/O2_1), U2.13 (IO12)
VBAT: C2_BAT.1, MCP73831.3 (VBAT), Q1.3 (D), TP3.TP, U4.2 (CELL), U4.3 (VDD)
VBUS: C1_BAT.1, C4_USB.1, C5_USB.1, CHG_LED.A, D1.5 (VBUS), D2.2 (ANODE), MCP73831.4 (VIN), PFMF.050.1.2, Q1.1 (G), R1_PWRUSB.2, TP14.TP
VRTC: C8.1, C10_SUPERCAP.2, R_CAPACITOR.1, U3.14 (VBAT)
VUSB: J2.A4, J2.A9, J2.B4, J2.B9, PFMF.050.1.1

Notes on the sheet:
USB C connector & ESD protection
LDO Voltage Regulator
SD Card
ESP32 C6
Li-Po Battery Charging Controller
E-Paper Drive Circuit
Display Type Selector
E-Paper Display Header
EPD Power
Environmental Sensor BME688
Voltage Supervisor + Reset & Boot / IO Button
Battery Charge Level
RTC Module DS3231SN
Test Pads
Qwiic / Stemma QT
SPI ESD Protection Lines
External NOR Flash 64MB

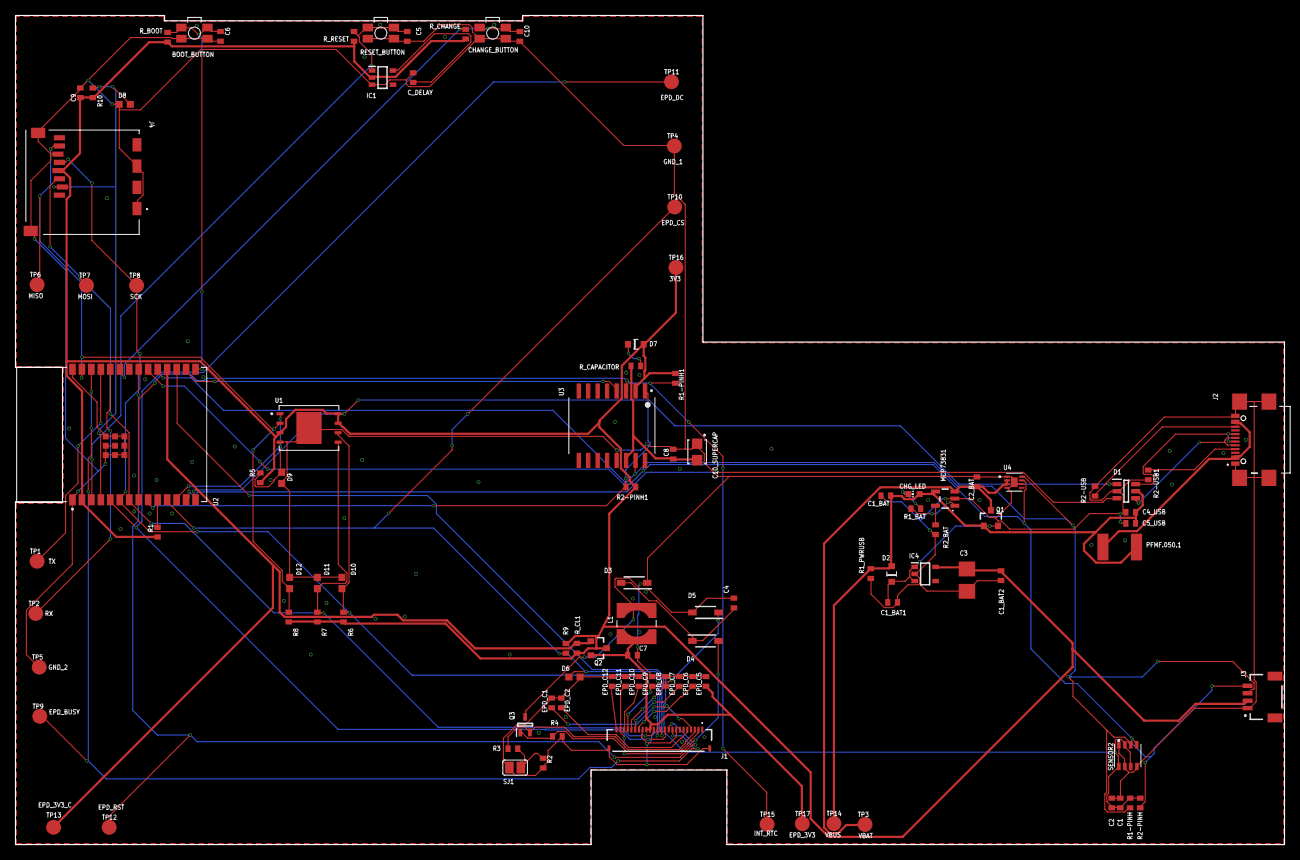
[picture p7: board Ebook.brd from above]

Board: 2 copper layers, 170.2 x 111.2 mm, 103 parts (0 on the bottom side), 55 nets.

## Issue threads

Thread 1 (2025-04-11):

PCB thickness

petrica913, 2025-04-11:
# Issue
The PCB thickness should be 1mm not 1.6mm as it wouldn't fit in the case.
# Fix
This can be fix by going to *Rules->Preferences->Layer Stack->Dielectric*

Closed 2025-04-14.

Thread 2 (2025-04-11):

Unfilled areas in GND plane (GND pour)

petrica913, 2025-04-11:
# Issue
A few areas in GND planes (top and bottom) that are unfilled
# Images
- There are some areas on the top plane that are not filled

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

- As well as on the bottom plane, it can be seen that is not completely filled

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

# Fixes
Can be easily fixed by adding some vias between the planes on the GND signal

Closed 2025-04-14.

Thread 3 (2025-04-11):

90 degrees routes

petrica913, 2025-04-11:
# Issue
There are a few 90 degrees  routes on the PCB
# Fix
They can be easily fixed by modifying the routes

Closed 2025-04-14.

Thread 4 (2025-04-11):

Missing Labels on the Schematic

petrica913, 2025-04-11:
# Issue
In the schematic, there are missing some labels for the U4 component, meaning that the component will not be correctly connected on the PCB
# Image

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

Closed 2025-04-14.

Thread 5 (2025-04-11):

VBAT width

petrica913, 2025-04-11:
# Issue
VBAT should be 0.3mm in width, as it's a power line, but it's only 0.15mm.

Closed 2025-04-14.

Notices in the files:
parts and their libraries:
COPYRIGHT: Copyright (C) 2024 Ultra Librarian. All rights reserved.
